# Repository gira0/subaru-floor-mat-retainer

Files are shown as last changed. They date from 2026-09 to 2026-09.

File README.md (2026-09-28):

# Subaru Floor Mat Retainer – Parametric OpenSCAD Replacement

Printable replacement for the Subaru floor mat retainer / hook, OEM part number **J501EAJ000** (EU) / **J501SAJ300** (US).
The original is hard to get and expensive to ship, so this is a parametric rebuild you can print yourself.

**Tested in:** Subaru XV (European Crosstrek), 2014, 2.0D 147 PS. It fits and holds the mat firmly.
The two originals (left/right) are identical, not mirrored, so one model covers both sides.

The model was measured from an original part with calipers and refined over two test prints.
It was designed with help from Claude (Anthropic's AI assistant) in Claude Code.

**Printables:** https://www.printables.com/model/1858866
**GitHub (source):** https://github.com/gira0/subaru-floor-mat-retainer

| File | Purpose |
|---|---|
| `bracket.scad` | The OpenSCAD model. All dimensions are at the top of the file. |
| `bracket.stl` | Ready-to-print file, already oriented for printing |
| `dimensions.drawio` | Dimension drawing with all letters. Open with [app.diagrams.net](https://app.diagrams.net) or the draw.io app |
| `dimensions.svg` | The same drawing as an image |
| `preview/` | Renders of the model |
| `tools/make_drawing.py` | Regenerates the drawing |
| `printables/` | Listing text (`DESCRIPTION.md`) and render images for printables.com |

## What the part looks like

It is a **single injection-moulded plastic part** (not sheet metal): a flat strip with a step in the middle.

```
      Pin                                Clip
       ▄                                  ▼
       █                     ┌────────────┬─────┐
  ─────┴──────────┐         /              Hook │
  straight part   └────────┘ ← step             ▼
```

- **Pin**: mushroom button. The eyelet of the floor mat goes over it.
- **Step**: the strip bends up at an angle and then continues straight.
- **Clip**: a plug on the underside that is pushed into the hole in the car floor. Seen from below it is a plus shape with thin lamella plates.
- **Hook**: the end bent down by 90°. It grips under an edge.

## Dimensions

The letters are the same in `dimensions.drawio`, here and in `bracket.scad`.

| | What | Value | Status |
|---|---|---|---|
| A | Strip thickness | 2.3 mm | measured |
| B | Strip width | 20 mm (19.93) | measured |
| C | Overall length, part lying flat: pin end to the very outside of the hook (over the rib) | 147.9 mm | measured |
| D | Straight section at the pin end, up to where the step starts | 51 mm | adjusted after test print (measured: 56) |
| E | How much higher the upper section sits | 30 mm | measured |
| F | Length of the step, measured horizontally | 50 mm | adjusted after test print (measured: 45) |
| G | Slope angle | 35.6° | adjusted: flatter, same bend radius (measured: 40°) |
| H | Hook depth: top of strip to hook tip | 14.9 mm | measured |
| I | Hook angle | 90° | measured |
| J | Pin centre to strip end | 10 mm | measured |
| K / L | Pin shaft / pin head diameter | 5 / 9 mm | measured |
| M / N | Top of strip to underside of head / head height | 15 / 4 mm | measured |
| O | Clip centre to outside of hook | 20 mm | measured |
| P | How far the clip sticks out below | 17.5 mm | measured |
| Q | Clip: lamella size (rounded square) | 6.7 mm | measured |
| R / S | Clip: width of one plus web / size of the plus | 2.2 / 7 mm | measured |
| T | Number of lamellae | 4 | measured |
| U | Rib: width | 3 mm | measured |
| V | Rib: height above the strip on the slope | 4 mm | measured |
| W | Rib: height above the strip on the upper (clip) section | 2 mm | measured |
| Z | Rib on the straight pin section: total height, centred in the strip | 5.5 mm | measured |
| a | Cross struts: pin centre to centre of the 2nd strut | 24.6 mm | adjusted after test print (measured: 21.6) |
| b | Cross strut: thickness (lengthwise) | 3 mm | measured |
| c | Cross strut: height on the back | 2 mm | measured |
| d | Cross strut: length across the strip | 20 mm (full width) | measured |
| e | Clip: lamella spacing (centre to centre) | 2.5 mm | adjusted, tested in the car (measured: 1.8) |
| f | Clip: solid block right at the strip | 1 mm | measured |
| g | Clip: lamella thickness | 0.6 mm | measured |
| h | Clip: lamella corner radius | 1.5 mm | *estimate* |
| i | Clip: length of the blunt tip | 3 mm | measured |
| j | Clip: width of the plus at the very tip | 1.5 mm | *estimate* |
| k | Dome (pin side, opposite the clip): diameter | 15 mm | measured |
| l | Dome: height at the centre | 2 mm | measured |
| m | Stop block at the hook tip: length | 3 mm | measured |

*Estimate* means: not measured, derived from photos or by eye.

**The bend radius of the step does not need measuring.** It follows from E, F and G (about 11.5 mm inside).

**Rounded end:** the pin end is a half circle with a radius of half the strip width, and the pin sits at its centre, so J = B/2.

**Rib:** the stiffening rib (U, 3 mm wide) runs lengthwise along the middle of the strip.
- On the straight pin section it sits centred in the strip: 5.5 mm tall (Z), so it sticks out 1.6 mm on both sides and merges into the pin. On the back it runs past the pin all the way to the rounded end.
- It is one continuous web of constant height. In the bend at the foot of the slope it moves up and simply passes through the strip: on the back it dips into the strip, on top it grows to the 4 mm of the slope (V). Its top edge follows a round arc there (`rib_fillet1`, radius 8.5 mm, estimate).
- In the bend to the upper section its top edge goes from 4 to 2 mm (W) in a round arc (`rib_fillet`, radius 15 mm, estimate).
- It then runs around the outside of the hook to the tip, where it ends in a stop block (m, 3 mm long) that spans the full strip width and is flush with the rib.
- `rib_side = -1` moves the rib to the clip side.

**Clip:** right at the strip sits a 1 mm solid block (f), followed by 4 thin lamellae (0.6 mm, g) with equal gaps (spacing e).
Then comes a plus of two crossed webs (R × S) whose last 3 mm taper to a blunt tip (i).
The clip length P = 17.5 mm is measured from the underside of the strip.

**Dome:** opposite the clip, on the pin side of the strip, is a flat round dome (15 mm Ø, 2 mm high at the centre). It fades out towards its rim and merges with the rib.

**Cross struts:** on the back of the pin end there are two transverse webs, one directly under the pin and one 24.6 mm further (a). They can be switched off with `struts`.

### Changing dimensions

1. Open `bracket.scad` in OpenSCAD.
2. Find the line with the matching letter at the top, e.g. `hook_depth = 14.9; // H …`, and change the number.
   Or use **Window → Customizer**, which shows an input field for every dimension.
3. Render with F6, then **File → Export → STL**.

From the command line:

```sh
openscad -o bracket.stl bracket.scad
openscad -D hook_depth=16 -o bracket.stl bracket.scad   # override a single value
```

## Material and printing

**Material:**
- **Test fit:** PLA+ works well and is what the tested part was printed in. It is rigid, so the clip is tight going in (it needed a firm push with the foot) but then sits very securely.
- **Final part:** PLA+ softens at about 55–60 °C, which a car interior easily reaches in summer. Use **PETG**, **ASA** or **TPU** for a part that stays in the car.
- **TPU 95A** gives the flex of the original but is softer: the hook grips less and the clip lamellae give way more easily. If it is too soft, increase `t` (A) by 0.5–1 mm or make the rib stronger (`rib_w`, `rib_ramp`).
- For rigid materials (PETG, PLA+) you can make the clip easier to insert by reducing the lamella size `clip_fin_sz` (Q) from 6.7 to about 6.3 mm.
- If the clip does not hold in your car, `clip_style = "hole"` replaces it with a screw hole.

**Orientation: on its side** (the STL is already saved this way).
The strip width (20 mm) becomes the print height, so the extrusion lines run through all bends and the bends are not loaded across layer lines.
The strip needs no support; only the pin and the clip stick out sideways and need some.

**Slicer notes (OrcaSlicer, tested on an Anycubic Kobra S1):**
- 0.4 mm nozzle, 0.2 mm layers
- 4–5 walls (the thin strip is effectively solid), 100 % infill for TPU / 40 % is fine for PLA+ and PETG
- Tree support, "on build plate only", top Z distance 0.2–0.25 mm
- Brim 3–5 mm, because the contact area is narrow
- **Enable "Detect thin walls"** (Quality tab). Otherwise the 0.6 mm clip lamellae are left out. Check in the slice preview. If it still fails, set `clip_fin_t` to 0.8.
- TPU: 20–30 mm/s, max. volumetric flow about 3–4 mm³/s, short slow retraction, dry the filament first

## Modelling assumptions

- The strip has the same thickness and width everywhere.
- Both bends of the step have the same radius.
- The pin head is a disc whose rim is fully rounded top and bottom (radius = half the head height).
- The small nubs on the edges of the original are not modelled; they look like moulding marks.

## Technical note: clean mesh

The strip and the rib are each generated as one closed mesh along the path (`sweep_mesh`), not from many `hull()` pieces.
The piecewise version produced over 3000 non-manifold edges at the bends in OpenSCAD 2021, which OrcaSlicer complains about.
Where parts would otherwise touch exactly, they overlap slightly or are offset by 0.001 mm for the same reason.
The current STL has 0 non-manifold edges, for all variants of `clip_style` and `clip_at_tip`.

## License

This project is licensed under [Creative Commons Attribution-ShareAlike 4.0 (CC BY-SA 4.0)](https://creativecommons.org/licenses/by-sa/4.0/).
You may print, share, modify and also sell it, as long as you give credit and share modified versions under the same license.

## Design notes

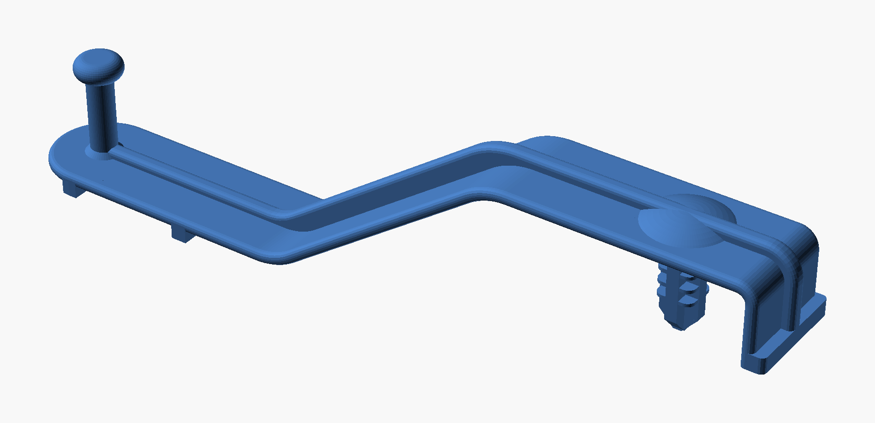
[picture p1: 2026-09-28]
printables/01-overview.png

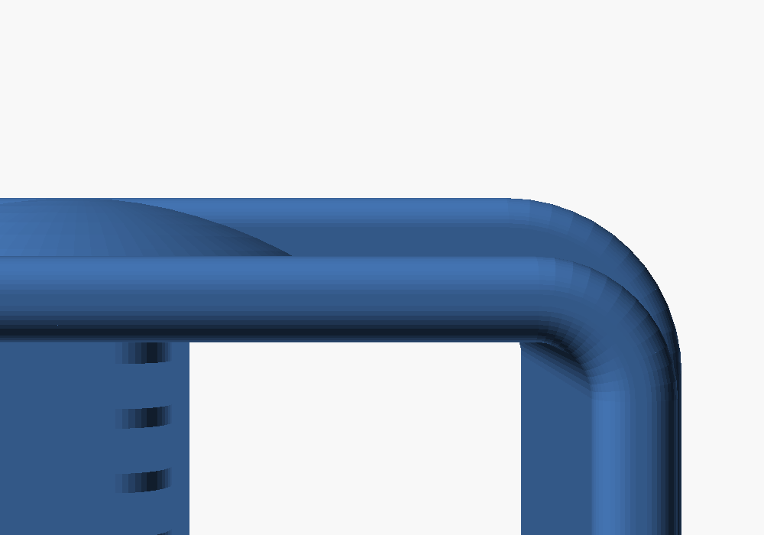
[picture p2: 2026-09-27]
preview/rib-hook.png

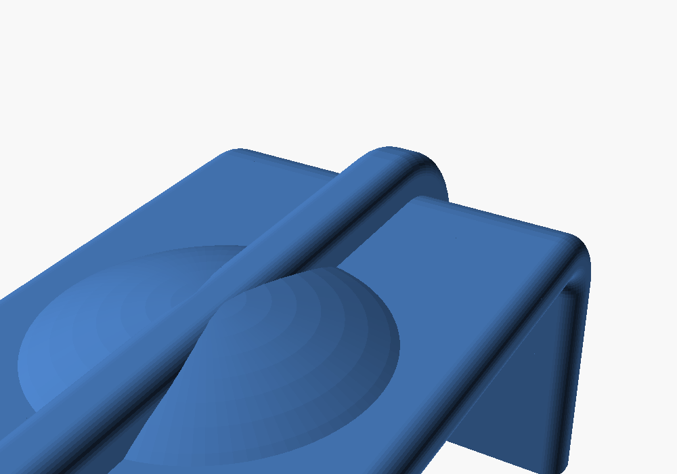
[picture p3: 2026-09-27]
preview/rib-hook2.png

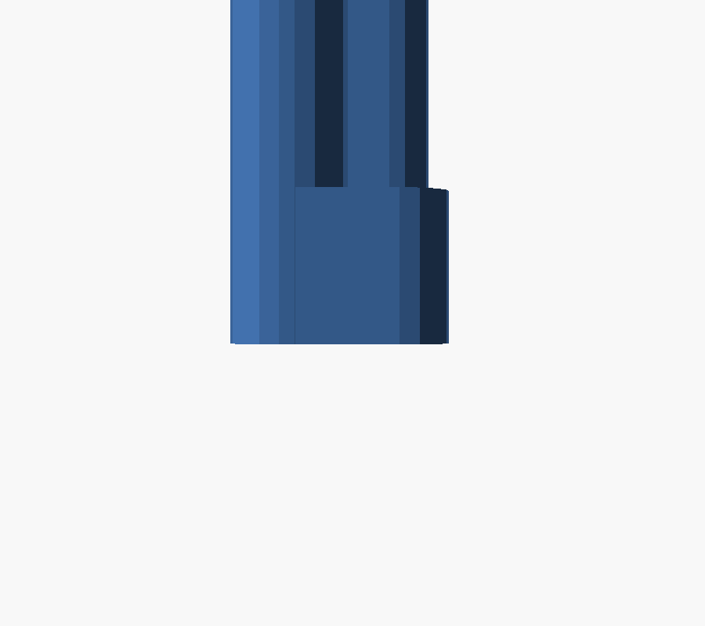
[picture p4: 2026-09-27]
preview/hook-stop.png

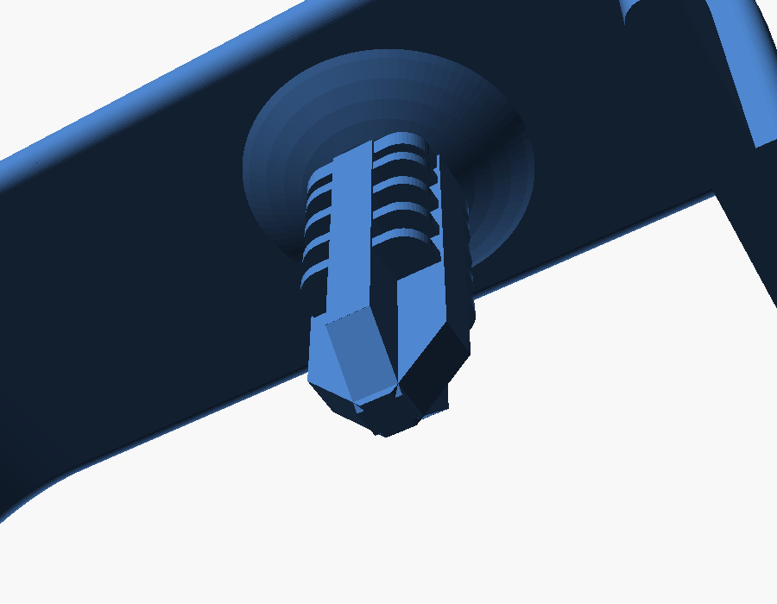
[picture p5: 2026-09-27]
preview/clip-below.png

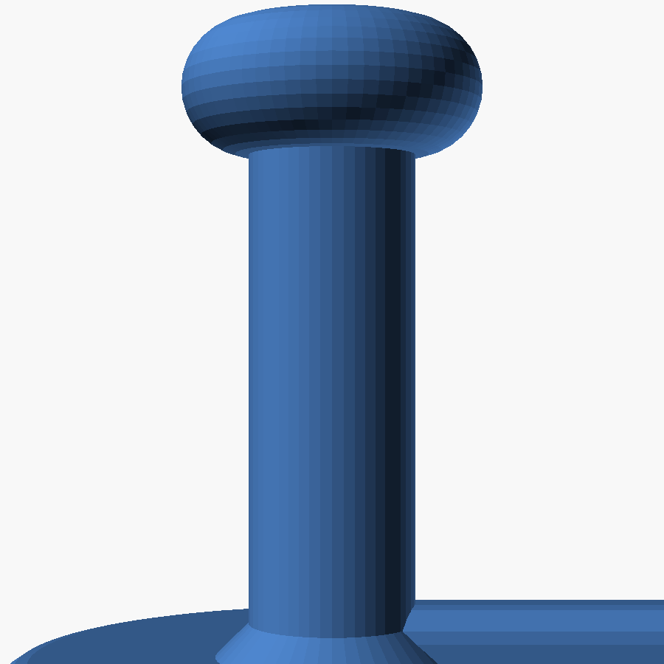
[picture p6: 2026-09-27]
preview/pin.png

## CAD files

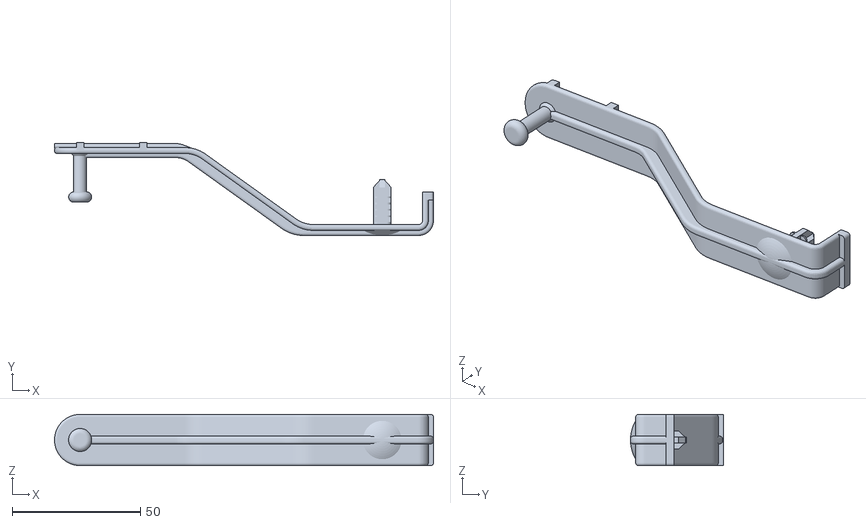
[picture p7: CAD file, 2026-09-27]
bracket.stl
147.9 x 36.3 x 20.0

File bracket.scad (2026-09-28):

// Subaru floor mat retainer (OEM J501EAJ000 / J501SAJ300) – parametric replacement
// Test-fitted in a Subaru XV / Crosstrek (EU) 2014, 2.0D.
//
// The letters (A, B, C …) match the dimension drawing dimensions.drawio and the
// table in README.md.
//
//   measured = taken from the original part with calipers
//   adjusted = measured, then corrected after a test print
//   ESTIMATE = not measured, derived from photos / by eye
//
// Coordinates: X = length, Y = width, Z = height (pin points up).

/* [Strip: the flat, long plastic strip] */
t           = 2.3;    // A  measured    strip thickness
w           = 20;     // B  measured    strip width (19.93, rounded)
L_total     = 147.9;  // C  measured    overall length, part lying flat: pin end to the very outside of the hook (over the rib)
L_lower     = 51;     // D  adjusted    straight section at the pin end, up to where the slope starts
corner_r    = 1;      //    cosmetic    edge rounding
// The pin end is a half circle (radius = half the width); the pin sits at its centre.

/* [Step: the sloped offset in the middle] */
rise        = 30;     // E  measured    how much higher the upper section sits than the pin section
ramp_run    = 50;     // F  adjusted    length of the step (measured horizontally, bend to bend)
ramp_angle  = 35.6;   // G  adjusted    slope angle in degrees
// The bend radius of the step does not need measuring; it follows from E, F and G.

/* [Hook: the end bent downwards] */
hook_depth  = 14.9;   // H  measured    hook depth (top of strip to hook tip)
hook_angle  = 90;     // I  measured    hook angle: 90 = square, more than 90 = tip points slightly inwards
hook_stop   = 3;      // m  measured    stop block at the hook tip: length; full width, flush with the rib on the outside
hook_ri     = 1.5;    //    cosmetic    inner radius of the hook bend (small = sharp corner)

/* [Pin: the mushroom button the mat eyelet goes over] */
pin_x       = 10;     // J  measured    pin centre to strip end (= centre of the rounded end)
pin_d       = 5;      // K  measured    shaft diameter
pin_head_d  = 9;      // L  measured    head diameter
pin_neck    = 15;     // M  measured    top of strip to underside of head
pin_head_h  = 4;      // N  measured    head height (fully rounded top and bottom)

/* [Clip: the plug underneath that goes into the hole in the floor] */
// Seen from below it is a plus of two crossed webs. Right at the strip a 1 mm solid block,
// then thin lamella plates (rounded squares), then the plus-shaped neck down to a blunt tip.
// Opposite, on the pin side of the strip, sits a flat round dome.
clip_style  = "plus"; // [plus:plus clip with lamellae, hole:hole for a screw, none:nothing]
clip_x      = 20;     // O  measured    clip centre to the very outside of the hook
clip_len    = 17.5;   // P  measured    how far the clip sticks out below (from the strip)
clip_fin_sz = 6.7;    // Q  measured    lamella size (rounded square, edge to edge)
clip_arm    = 2.2;    // R  measured    width of one plus web
clip_plus   = 7;      // S  measured    plus size (length of one web)
clip_fins   = 4;      // T  measured    number of lamellae
clip_pitch  = 2.5;    // e  adjusted    lamella spacing (centre to centre; measured 1.8, 2.5 tested in the car)
clip_base   = 1;      // f  measured    solid block right at the strip
clip_fin_t  = 0.6;    // g  measured    lamella thickness (0.6 is tight for a 0.4 nozzle, see README)
clip_fin_r  = 1.5;    // h  ESTIMATE    lamella corner radius
clip_tip    = 3;      // i  measured    length of the blunt tip
clip_tip_w  = 1.5;    // j  ESTIMATE    width of the plus at the very tip (blunt end)
clip_at_tip = false;  //    false: block + lamellae right at the strip (like the original); true: at the tip
clip_boss_d = 15;     // k  measured    diameter of the round dome (pin side, opposite the clip)
clip_boss_h = 2;      // l  measured    dome height at the centre (same as rib W)
hole_d      = 5;      //    only for clip_style = "hole": hole diameter

/* [Rib: the stiffening web along the middle of the strip] */
// The rib runs lengthwise along the middle of the strip. On the straight pin section it sits
// centred in the strip and sticks out equally on both sides (total height Z). In the bend at
// the foot of the slope it moves to the pin side: on the slope it sticks out V, on the upper
// section only W, and it runs around the outside of the hook down to the hook tip.
rib         = true;   //    rib on/off
rib_side    = 1;      //    1 = pin side, -1 = clip side
rib_w       = 3;      // U  measured    rib width
rib_ramp    = 4;      // V  measured    how far the rib sticks out on the slope
rib_upper   = 2;      // W  measured    how far the rib sticks out on the upper (clip) section
rib_fillet  = 15;     //    ESTIMATE    radius of the rib edge transition from V to W at the 2nd bend
rib_fillet1 = 8.5;    //    ESTIMATE    radius of the rib edge transition at the 1st bend (foot of the slope)
rib_mid     = 5.5;    // Z  measured    total rib height on the straight pin section, centred in the strip

/* [Cross struts on the back, at the pin end] */
// Two transverse webs on the back: one directly under the pin, one further towards the slope.
struts      = true;   //    cross struts on/off
strut_gap   = 24.6;   // a  adjusted    pin centre to centre of the 2nd strut (measured 21.6, +3 after test print)
strut_t     = 3;      // b  measured    strut thickness (measured lengthwise)
strut_h     = 2;      // c  measured    how far a strut sticks out on the back
strut_len   = 20;     // d  measured    strut length (across the strip) = full strip width

/* [Output] */
print_on_side = true; // true: part lies on its side (recommended, see README)
$fn = 48;
arc_steps = 12;       // segments per bend

// ---------------------------------------------------------------------------
// Derived values (strip centre line)
a   = ramp_angle;
R1  = (ramp_run - rise / tan(a)) / (2 * tan(a/2));   // centre-line radius of the step, from E, F, G
R3  = hook_ri + t/2;               // centre-line radius of the hook
bend_ri = R1 - t/2;
L_ramp  = (rise - 2*R1*(1 - cos(a))) / sin(a);
hook_rib = (rib && rib_side > 0) ? rib_upper : 0;   // rib sits on the outside of the hook
L_band  = L_total - hook_rib;                        // outside of the strip at the hook
L_upper = L_band - L_lower - ramp_run - R3 - t/2;
L_hook  = hook_depth - t/2 - R3;

assert(bend_ri > 0, "F (ramp_run) too short for E (rise) and G (ramp_angle)");
assert(L_ramp  > 0, "F (ramp_run) too long for E (rise) and G (ramp_angle)");
assert(L_upper > 0, "C (L_total) too small for the other dimensions");
assert(L_hook  > 0, "H (hook_depth) too small");
assert(pin_head_d > pin_d, "L (head) must be larger than K (shaft)");
assert(rib_mid > t, "Z (rib_mid) must be larger than the strip thickness A");

// Path as turtle commands: ["line", length] | ["arc", radius, angle (+ = upwards)]
path = [
    ["line", L_lower - pin_x],
    ["arc",  R1,  a],
    ["line", L_ramp],
    ["arc",  R1, -a],
    ["line", L_upper],
    ["arc",  R3, -hook_angle],
    ["line", L_hook]
];

// Turtle -> list of [x, z, heading, segment index]; lines split into ~1 mm steps (for the rib)
function step_pts(p, c, i) =
    c[0] == "line"
      ? let(n = max(1, ceil(c[1] / 1)))
        [for (k = [1:n]) [p[0] + k*c[1]/n*cos(p[2]), p[1] + k*c[1]/n*sin(p[2]), p[2], i]]
      : [for (k = [1:arc_steps]) let(
            da = c[2]/arc_steps,
            pk = arc_pos(p, c[1], da, k))   // position after k chord steps
          [pk[0], pk[1], p[2] + k*da, i]];

function arc_pos(p, R, da, k) =
    k == 0 ? [p[0], p[1]]
           : let(q = arc_pos(p, R, da, k-1),
                 h = p[2] + (k-1)*da + da/2,
                 ch = 2*R*sin(abs(da)/2))
             [q[0] + ch*cos(h), q[1] + ch*sin(h)];

function walk(cmds, p, i = 0) =
    i >= len(cmds) ? []
    : let(s = step_pts(p, cmds[i], i), last = s[len(s)-1])
      concat(s, walk(cmds, last, i+1));

start = [pin_x, t/2, 0, 0];     // strip starts at the pin; the half-circle end sits before it
pts = concat([start], walk(path, start));

// arc length from the pin for each point, and x position -> arc length (before the hook)
function cum(i) = i == 0 ? 0 : cum(i-1) + norm([pts[i][0] - pts[i-1][0], pts[i][1] - pts[i-1][1]]);
S = [for (i = [0:len(pts)-1]) cum(i)];
x_to_s = [for (i = [0:len(pts)-1]) if (pts[i][3] <= 4) [pts[i][0], S[i]]];
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

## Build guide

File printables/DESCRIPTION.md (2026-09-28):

# Printables listing – copy & paste

Everything below is meant to be copied into the matching fields on printables.com.
Fields in [square brackets] still need your input.

---

## Name

Subaru Floor Mat Retainer Hook – J501EAJ000 / J501SAJ300 (parametric)

## Summary (short text under the title)

Printable Subaru floor mat retainer (J501EAJ000 / J501SAJ300). Tested in an XV/Crosstrek 2014. Parametric OpenSCAD.

(Printables cuts the summary at 120 characters; this one is 115.)

## Description

A printable replacement for the Subaru floor mat retainer: the hook that holds the floor mat in place, with a pin for the mat's eyelet and a clip that pushes into the hole in the car floor.

**OEM part numbers:** J501EAJ000 (EU) / J501SAJ300 (US)

**Tested in:** Subaru XV (European Crosstrek), 2014, 2.0D 147 PS. The printed part fits, clips in and holds the mat firmly.
The left and right originals are identical (not mirrored), so one model covers both sides.
Other Subaru models that use the same part number should fit too, but I have only tested the XV. Please post a make or a comment if it fits your car.

The original was hard to get and shipping it in was expensive, so I measured an original with calipers and rebuilt it as a parametric OpenSCAD model. It went through two test prints before it was "barely distinguishable" from the original.

### Printing

- **Orientation:** print it **on its side**, exactly as the STL is saved. That way all bends lie within the layers and do not break along layer lines.
- **Supports:** tree supports, "on build plate only", only needed for the pin and the clip.
- **Enable "Detect thin walls"** in your slicer (OrcaSlicer/PrusaSlicer: Quality tab). The clip lamellae are only 0.6 mm thick and are otherwise left out. Check the slice preview.
- Brim 3–5 mm helps, because the part stands on a narrow edge.
- 0.4 mm nozzle, 0.2 mm layers, 4–5 walls. 40 % infill is enough for PLA/PETG, 100 % for TPU.

### Material

- **PLA+** works well for a test fit (that is what the tested part is made of). It is rigid, so the clip is tight going in: it needed a firm push with the foot, then sits very securely.
- **For permanent use, print PETG, ASA or TPU.** PLA softens at 55–60 °C, which a parked car easily reaches in summer.
- **TPU 95A** gives the flexibility of the original but grips a bit less firmly.

### Customising (OpenSCAD)

`bracket.scad` is fully parametric. Every dimension is a named variable at the top of the file with a letter that matches the included dimension drawing (`dimensions.svg`). Open it in OpenSCAD and use **Window → Customizer**. Useful tweaks:
- Clip too tight in a rigid material: reduce `clip_fin_sz` (lamella size) from 6.7 to about 6.3 mm.
- Clip does not hold in your car: set `clip_style = "hole"` to get a screw hole instead.
- Too soft in TPU: increase the strip thickness `t` by 0.5–1 mm.

The exported STL is clean (0 non-manifold edges).

### Transparency

I designed this with help from Claude (Anthropic's AI assistant) in Claude Code. I took all the measurements from the original part and checked every step against it and against test prints. Claude wrote and refined the OpenSCAD model from those measurements.

## Files to upload

- `bracket.stl` – ready to print, already oriented
- `bracket.scad` – parametric source
- `dimensions.svg` – dimension drawing (optional; nice as an extra image or file)
- `README.md` – full dimension table and notes (optional)

## Images

- **Your own photos first** (Printables shows the first image as the cover): the print next to the original, and the part installed in the car.
- Then the renders from this folder: `01-overview.png`, `02-side.png`, `03-below.png`, `04-clip-hook.png`, `05-pin-end.png`,
  and the dimension drawing `06-dimensions.png`.
- The reference photos of the original used during design are not part of this repository; they are shop product photos and not ours to publish.

## Print settings (the form fields)

- Printer: Anycubic Kobra S1
- Rafts: No
- Supports: Yes (tree, build plate only – pin and clip)
- Resolution: 0.2 mm
- Infill: 40 % (PLA+/PETG), 100 % (TPU)
- Filament: PLA+ (test fit); PETG / ASA / TPU recommended for permanent use

## Category

Hobby & Makers → Automotive  *(or: Household → Replacement Parts, whichever fits better)*

## Tags

subaru, xv, crosstrek, floor mat, floormat, retainer, clip, hook, car, automotive, replacement, spare part, J501EAJ000, J501SAJ300, openscad, parametric

## License

Creative Commons – Attribution – ShareAlike (CC BY-SA 4.0)
(Printables: "Creative Commons — Attribution — Share Alike"; leave "exclude commercial use" off)

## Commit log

2026-09-27 Parametrischer Nachbau der Subaru Fußmatten-Halterung
    Stand nach dem zweiten PLA+-Probedruck: OpenSCAD-Modell (bracket.scad),
    STL, Maßzeichnung (masse.drawio/.svg, erzeugt von tools/make_drawing.py),
    README, Fotos des Originals und Vorschaubilder.
    [bracket.scad, bracket.stl]
2026-09-28 Translate model, README and drawing to English
    - bracket.scad: comments, customizer labels and messages in English;
    geometry unchanged (re-export is triangle-identical to bracket.stl)
    - README rewritten in English, cleaned up (removed stale rib_below and
    duplicated rib notes), adds tested car and PLA+ fit experience
    - masse.drawio/.svg renamed to dimensions.drawio/.svg, labels in English
    [bracket.scad]
2026-09-28 Add Printables listing text and render images
    printables/DESCRIPTION.md holds title, summary, description, print
    settings, tags and file list; images are clean OpenSCAD renders plus
    the dimension drawing as PNG. License still to be chosen.
2026-09-28 Shorten Printables summary to fit the 120-character limit
    Also ignore saved HTML pages; they contain account data.
2026-09-28 Switch license to CC BY-SA 4.0; confirm 2.5 mm lamella spacing
    Commercial use is now allowed (with credit, share-alike) so sellers can
    offer a tested design. Lamella spacing e = 2.5 mm is kept as tested in
    the car (measured value 1.8 mm noted).
    [bracket.scad]
2026-09-28 Add copy-paste description page for the Printables editor
    The Printables editor does not accept Markdown; this HTML page keeps
    bold, headings and lists when copied into it.
2026-09-28 Remove copy-paste description page after publishing
    The model is published on Printables (id 1858866); the helper page is
    no longer needed.
2026-09-28 Link the Printables page; keep reference photos out of the repo
